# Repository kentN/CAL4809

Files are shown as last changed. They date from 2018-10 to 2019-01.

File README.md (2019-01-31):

# CAL4809
ATmega4809 TimeKeeping Module with MemoryLCD

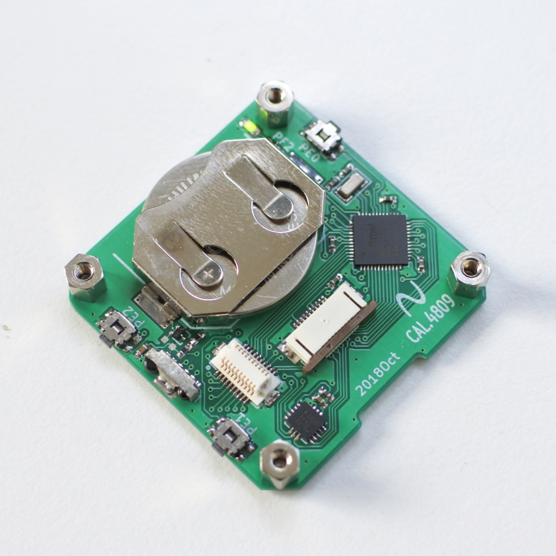
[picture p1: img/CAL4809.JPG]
PCB CAL4809

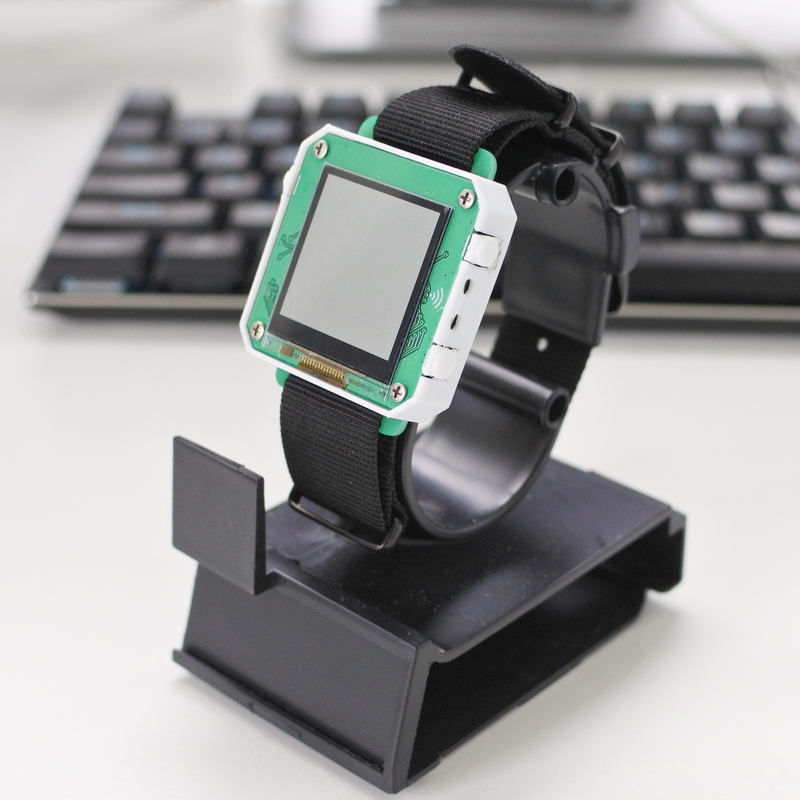
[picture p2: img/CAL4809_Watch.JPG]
WATCH CAL4809_Watch


----------

## Features ##

- ATmega4809 MCU (SRAM 6kB, FlashROM 48kB)
- Sharp Memory LCD (128x128pixcel or 96x96pixcel)
- 3 button
- Low Power Accelerometer ADXL362
- IrDA SIR Transceiver
- 32.768kHz External Crystal
- CR2032 Coin Cell battery (Diode OR option)
- External Connector(DF12-20p) 
- BUS UART(x2ch), SPI, I2C, GPIO/ADC(x8ch)

----------
## Applications ##

- DIY WristWatch
- Embedded Display&TimeKeeping module
- Motion Data Logger

----------

## Project Environment ##

- KiCad (5.0.1)
- Atmel Studio 7.0

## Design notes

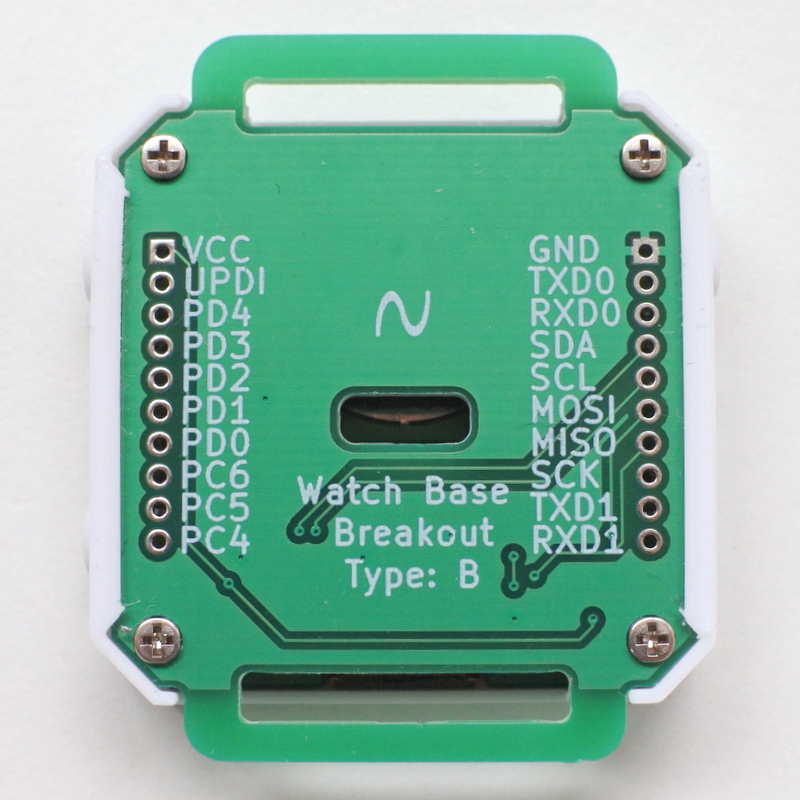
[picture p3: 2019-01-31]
img/CAL4809_breakout.JPG

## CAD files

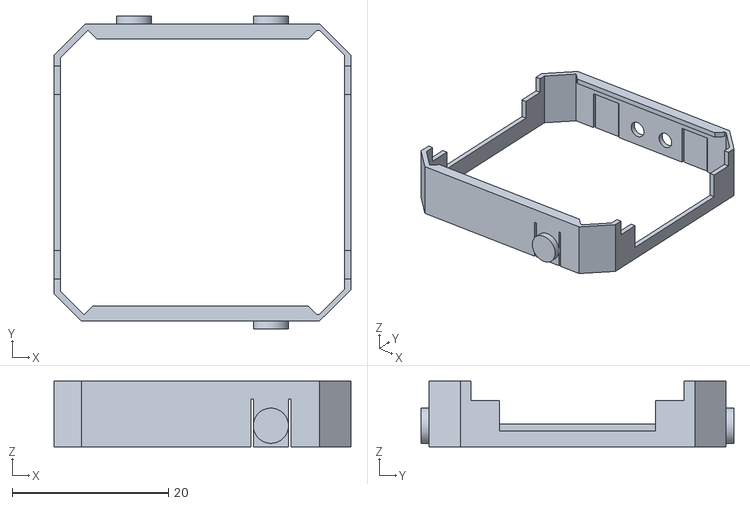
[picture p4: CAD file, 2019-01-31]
Hardware/3D/Watch_bumper.stl
38.0 x 40.0 x 8.40

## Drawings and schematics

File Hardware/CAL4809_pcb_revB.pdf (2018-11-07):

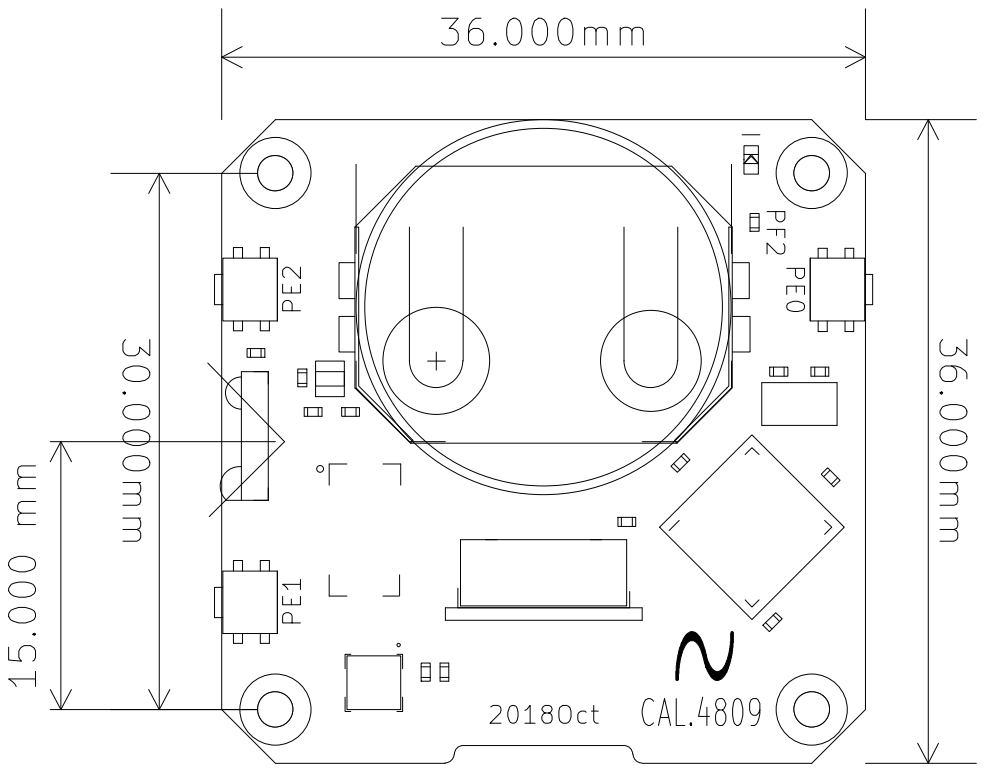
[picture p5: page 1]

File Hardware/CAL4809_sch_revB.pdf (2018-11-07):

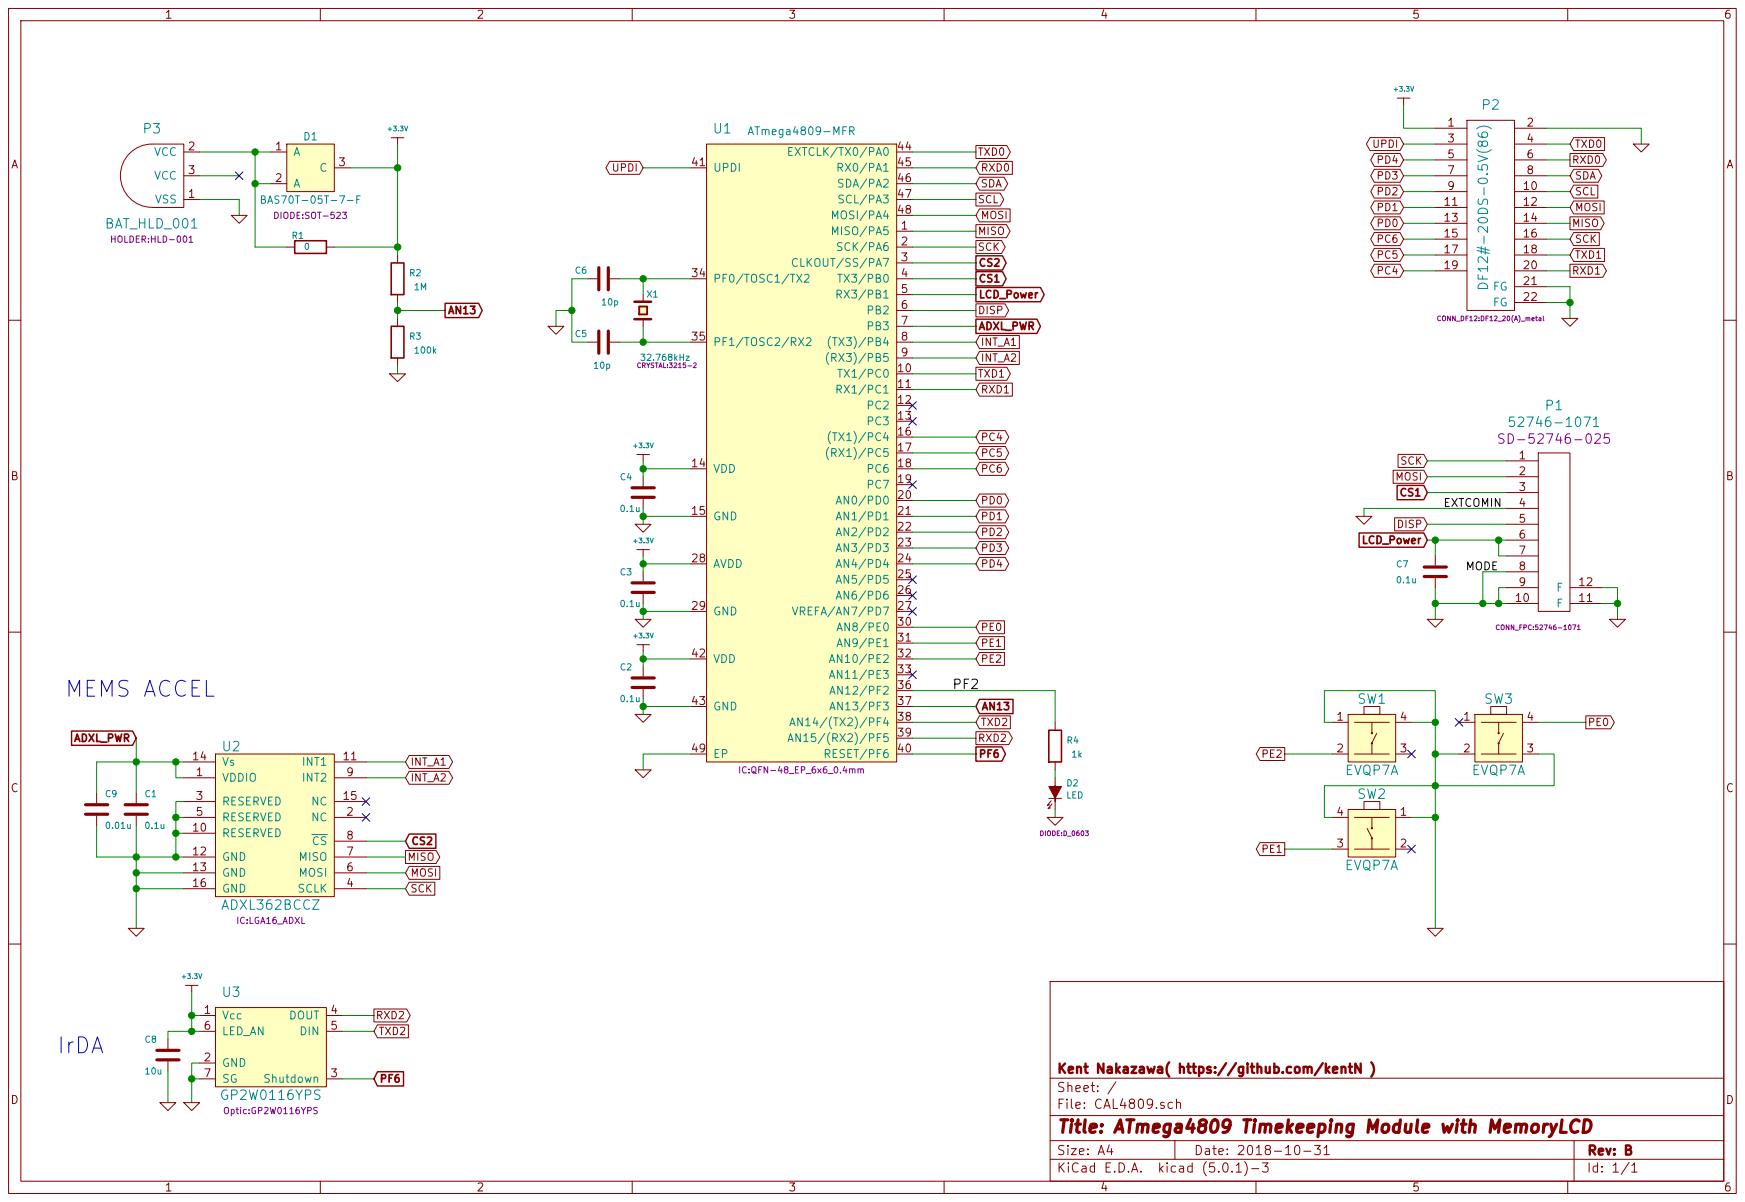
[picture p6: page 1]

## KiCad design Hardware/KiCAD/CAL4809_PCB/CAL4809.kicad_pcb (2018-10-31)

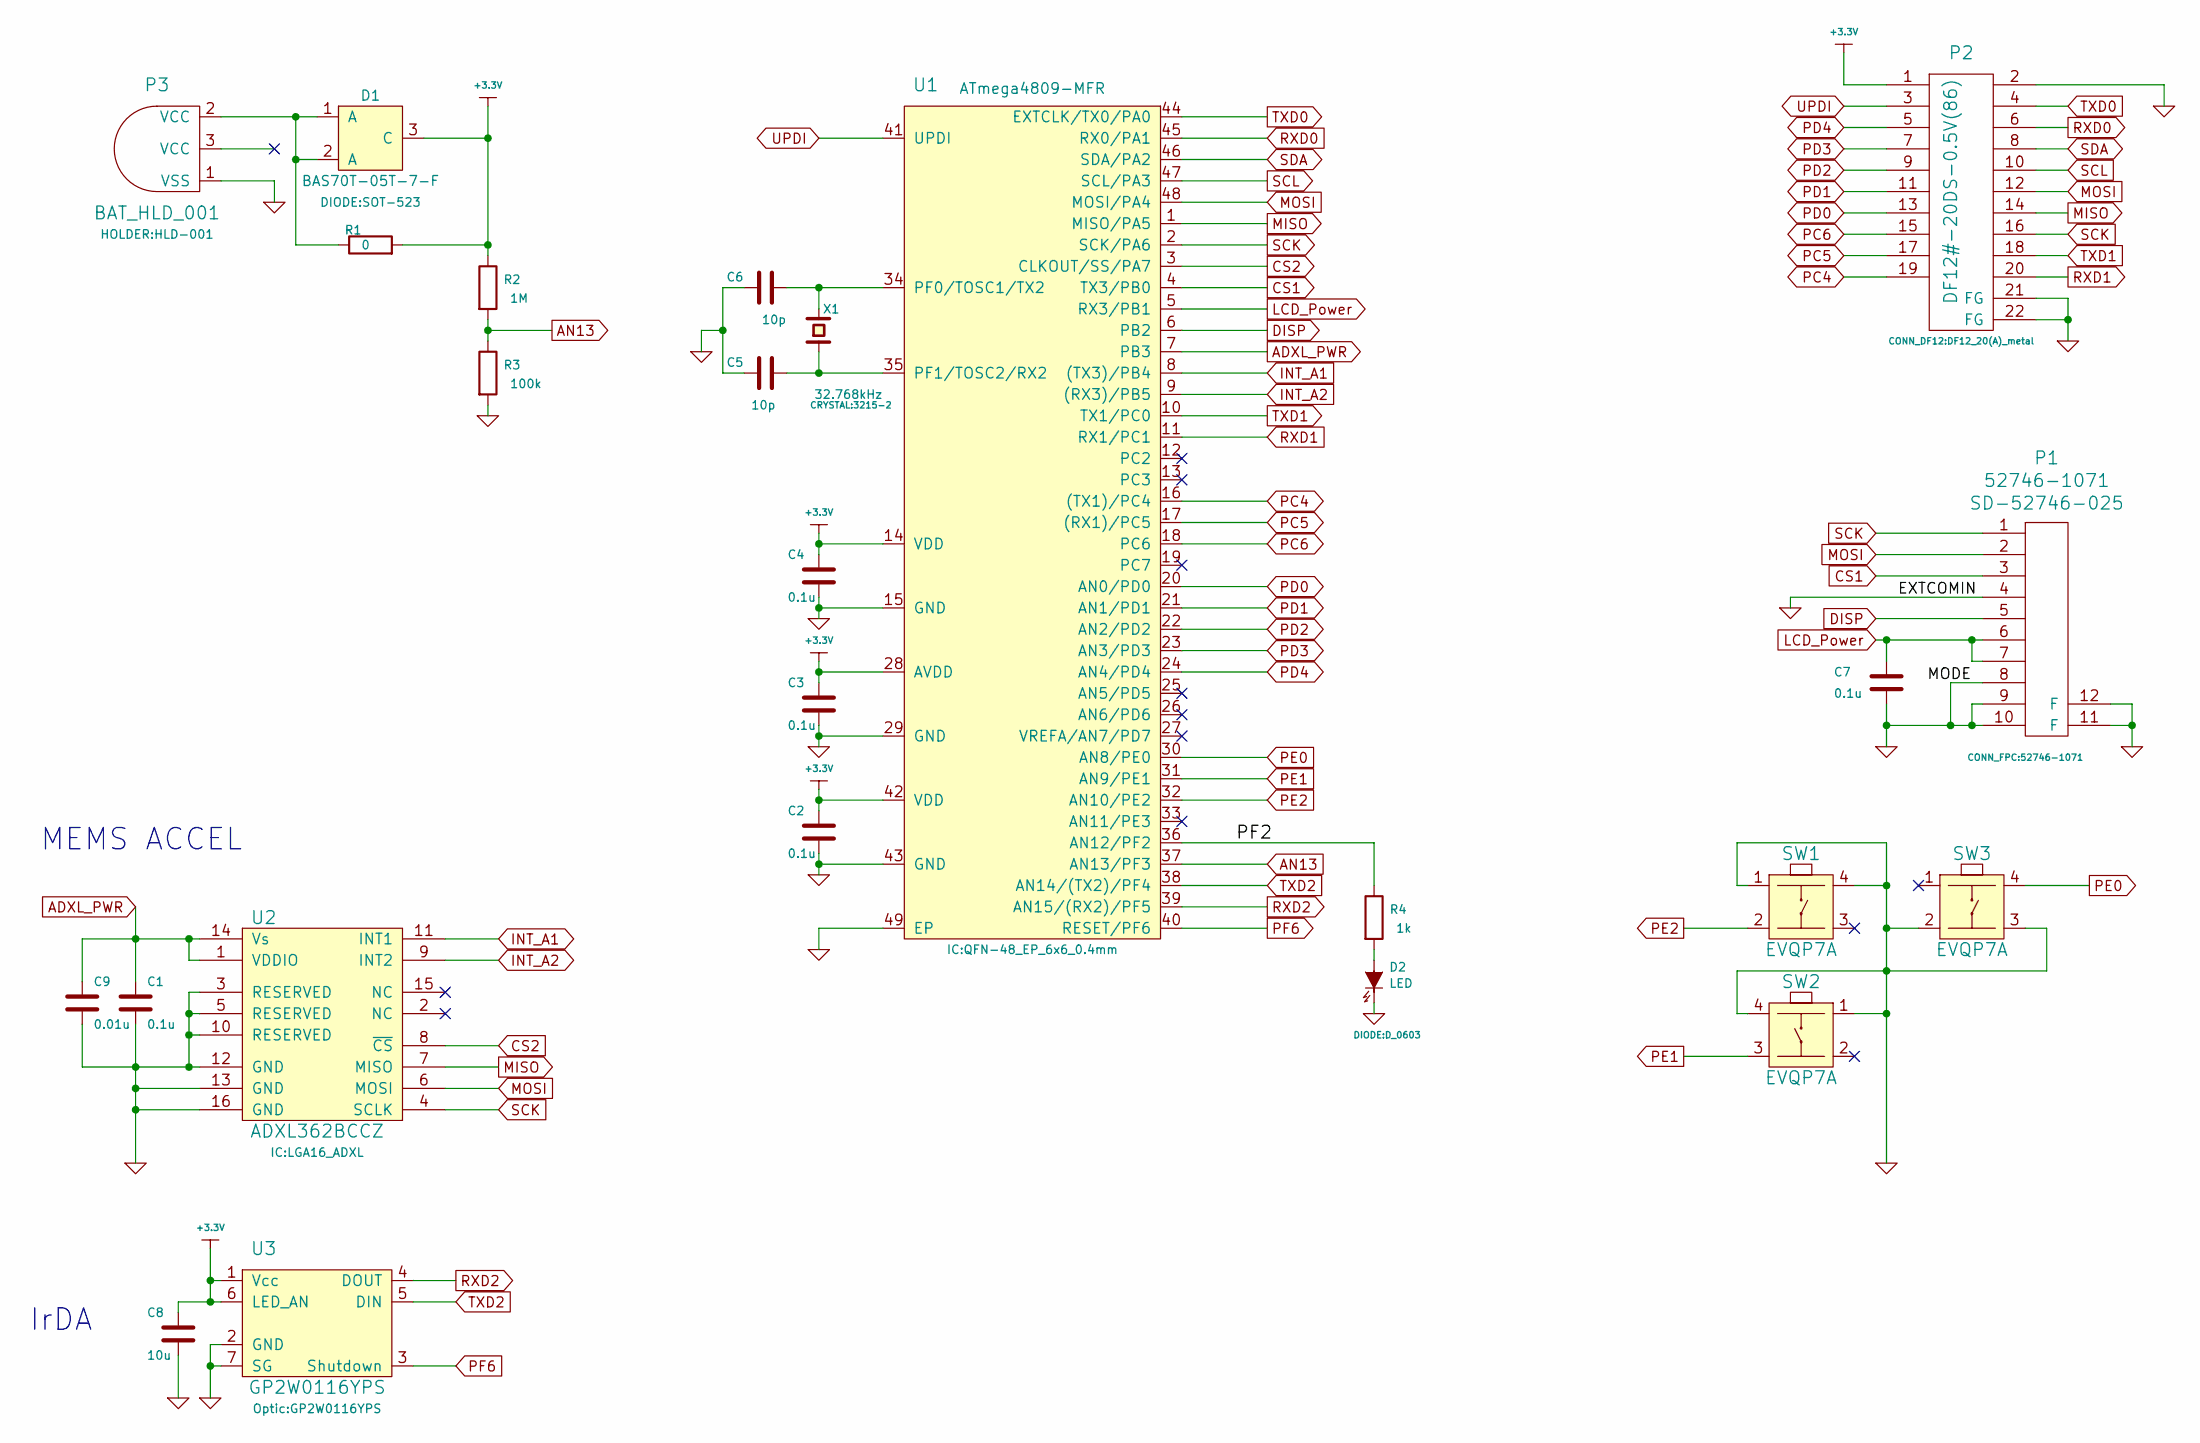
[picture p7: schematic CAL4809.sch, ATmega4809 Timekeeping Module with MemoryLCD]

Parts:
C1, C2, C3, C4, C7: 0.1u; 0402L
C5, C6: 10p; 0402L
C8: 10u; 0402L
C9: 0.01u; 0402L
D1: BAS70T-05T-7-F; SOT-523
D2: LED; D_0603
P1: 52746-1071
P2: DF12#-20DS-0.5V(86); DF12_20(A)_metal
P3: BAT_HLD_001; HLD-001
R1: 0; 0402L
R2: 1M; 0402L
R3: 100k; 0402L
R4: 1k; 0402L
SW1, SW2, SW3: EVQP7A
U1: ATmega4809-MFR; QFN-48_EP_6x6_0.4mm
U2: ADXL362BCCZ; LGA16_ADXL
U3: GP2W0116YPS
X1: 32.768kHz; 3215-2

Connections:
+3.3V: C2.1, C3.1, C4.1, C8.1, D1.3 (C), P2.1, R1.2, R2.1, U1.14 (VDD), U1.28 (AVDD), U1.42 (VDD), U3.1 (Vcc), U3.6 (LED_AN)
/PF2: R4.1, U1.36 (AN12/PF2)
ADXL_PWR: C1.1, C9.1, U1.7 (PB3), U2.1 (VDDIO), U2.14 (Vs)
AN13: R2.2, R3.1, U1.37 (AN13/PF3)
CS1: P1.3, U1.4 (TX3/PB0)
CS2: U1.3 (CLKOUT/SS/PA7), U2.8 (~CS)
DISP: P1.5, U1.6 (PB2)
GND: C1.2, C2.2, C3.2, C4.2, C5.2, C6.2, C7.2, C8.2, C9.2, D2.2 (K), P1.4, P1.8, P1.9, P1.10, P1.11 (F), P1.12 (F), P2.2, P2.21 (FG), P2.22 (FG), P3.1 (VSS), R3.2, SW1.1, SW1.4, SW2.1, SW2.4, SW3.2, SW3.3, U1.15 (GND), U1.29 (GND), U1.43 (GND), U1.49 (EP), U2.3 (RESERVED), U2.5 (RESERVED), U2.10 (RESERVED), U2.12 (GND), U2.13 (GND), U2.16 (GND), U3.2 (GND), U3.7 (SG)
INT_A1: U1.8 ((TX3)/PB4), U2.11 (INT1)
INT_A2: U1.9 ((RX3)/PB5), U2.9 (INT2)
LCD_Power: C7.1, P1.6, P1.7, U1.5 (RX3/PB1)
MISO: P2.14, U1.1 (MISO/PA5), U2.7 (MISO)
MOSI: P1.2, P2.12, U1.48 (MOSI/PA4), U2.6 (MOSI)
unnamed: C5.1, U1.35 (PF1/TOSC2/RX2), X1.1
unnamed: C6.1, U1.34 (PF0/TOSC1/TX2), X1.2
unnamed: D1.1 (A), D1.2 (A), P3.2 (VCC), R1.1
unnamed: D2.1 (A), R4.2
PC4: P2.19, U1.16 ((TX1)/PC4)
PC5: P2.17, U1.17 ((RX1)/PC5)
PC6: P2.15, U1.18 (PC6)
PD0: P2.13, U1.20 (AN0/PD0)
PD1: P2.11, U1.21 (AN1/PD1)
PD2: P2.9, U1.22 (AN2/PD2)
PD3: P2.7, U1.23 (AN3/PD3)
PD4: P2.5, U1.24 (AN4/PD4)
PE0: SW3.4, U1.30 (AN8/PE0)
PE1: SW2.3, U1.31 (AN9/PE1)
PE2: SW1.2, U1.32 (AN10/PE2)
PF6: U1.40 (RESET/PF6), U3.3 (Shutdown)
RXD0: P2.6, U1.45 (RX0/PA1)
RXD1: P2.20, U1.11 (RX1/PC1)
RXD2: U1.39 (AN15/(RX2)/PF5), U3.4 (DOUT)
SCK: P1.1, P2.16, U1.2 (SCK/PA6), U2.4 (SCLK)
SCL: P2.10, U1.47 (SCL/PA3)
SDA: P2.8, U1.46 (SDA/PA2)
TXD0: P2.4, U1.44 (EXTCLK/TX0/PA0)
TXD1: P2.18, U1.10 (TX1/PC0)
TXD2: U1.38 (AN14/(TX2)/PF4), U3.5 (DIN)
UPDI: P2.3, U1.41 (UPDI)

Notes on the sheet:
IrDA
MEMS ACCEL

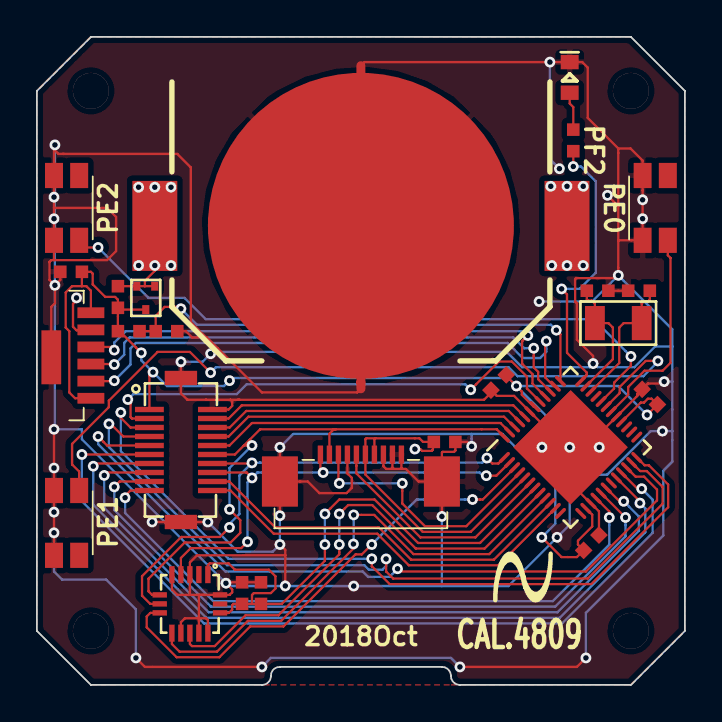
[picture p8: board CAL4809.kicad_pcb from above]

Board: 2 copper layers, 36.0 x 36.0 mm, 29 parts (0 on the bottom side), 39 nets.

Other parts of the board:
Drill_M2, Drill_M2#2, Drill_M2#3, Drill_M2#4: VAL**; Drill_M2

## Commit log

2018-10-31 add CAL4809 kicad files
    [CAL4809.kicad_pcb, CAL4809.sch]
2018-11-07 Update Hardware/CAL4809_sch_revB.pdf
    add schematic pdf
2018-11-07 Update Hardware/CAL4809_pcb_revB.pdf
    add board layout
